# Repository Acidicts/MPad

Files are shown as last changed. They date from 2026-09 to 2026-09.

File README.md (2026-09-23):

# M-Pad
### Media-Pad (Media-Hackpad)

A Hackpad but this time made for media with 3 dedicated keys for Back, Play/Pause, and Skip along with volume controls via a rotary encoder.
Powered by kmk on circuitpython

<div>
    assembled model
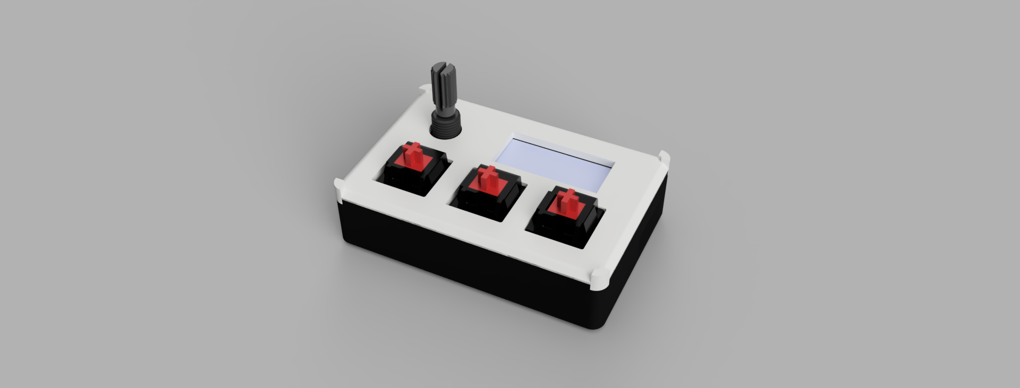
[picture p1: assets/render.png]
    
    <div style="display: inline-flex; justify-content: space-between; margin-top: 10px;">
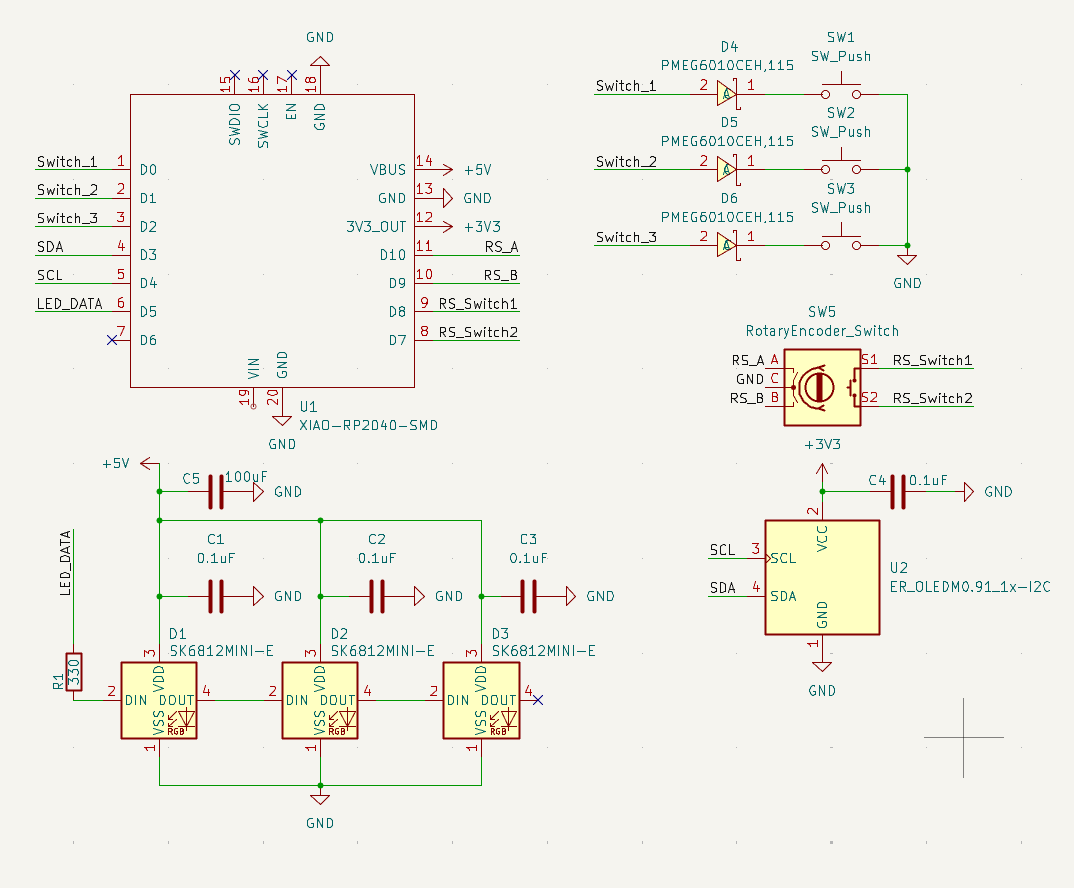
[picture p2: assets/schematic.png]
        
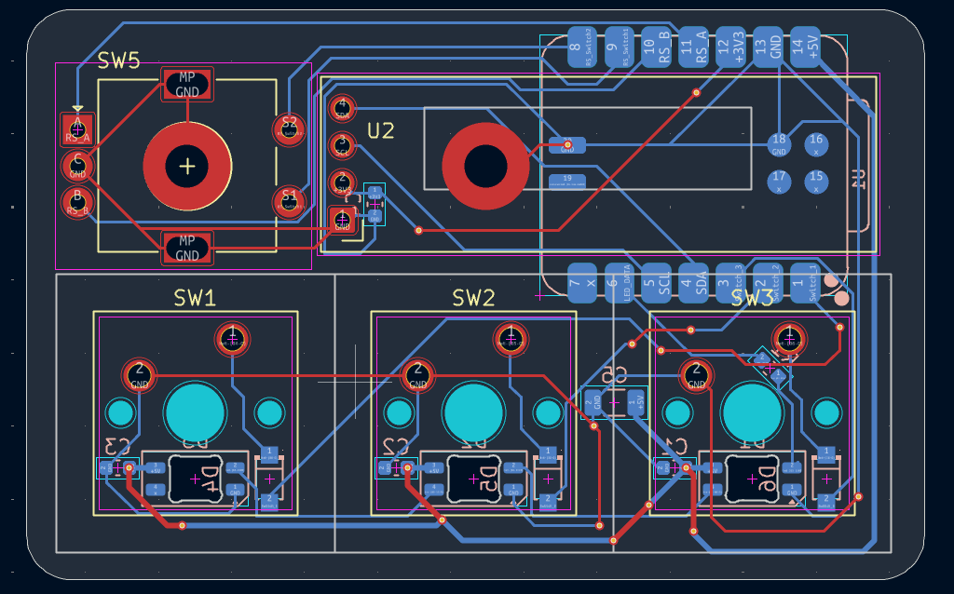
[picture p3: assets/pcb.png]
        
    </div>
</div>

### Case
- The lid is [here](./case/Lid.step)
- The case is [here](./case/Case.step)
- The Custom encoder knob is [here](./case/Encoder_Knob.step)
- The detachable stand that mounts in the two square holes in the back is [here](./case/Detachable_Stand.step)
- Fusion 360 file is [here](https://a360.co/4gD1b6e)

### Key Mappings
---
<div style="display: inline-flex; justify-content: space-between;">
    <div style="border-right: 1px solid #888; padding-right: 10px; margin-right: 10px;">
        <strong>Key Switches</strong>
        <table>
            <thead>
                <tr>
                    <th>Function</th>
                    <th>Key</th>
                </tr>
            </thead>
            <tbody>
                <tr><td>Back</td><td>KC.WBAK</td></tr>
                <tr><td>Play/Pause</td><td>KC.MPLY</td></tr>
                <tr><td>Skip</td><td>KC.WFWD</td></tr>
            </tbody>
        </table>
    </div>
    <div>
        <strong>Encoder Mapping</strong>
        <table>
            <thead>
                <tr>
                    <th>Function</th>
                    <th>Key</th>
                </tr>
            </thead>
            <tbody>
                <tr><td>Volume Down</td><td>KC.VOLD</td></tr>
                <tr><td>Volume Up</td><td>KC.VOLU</td></tr>
                <tr><td>Mute</td><td>KC.MUTE</td></tr>
            </tbody>
        </table>
    </div>
</div>

### BOM
---
- [BOM](./assets/BOM.csv)
- [LCSC Component BOM](./assets/LCSC_BOM.csv)

### Getting Started
1. Download the latest release of circuitpython from [here](https://downloads.circuitpython.org/bin/seeeduino_xiao_rp2040/en_GB/adafruit-circuitpython-seeeduino_xiao_rp2040-en_GB-10.3.0.uf2)
2. whilst powering the Seeed Studio XIAO RP2040, hold down the boot button and plug it into your computer. The board should show up as a USB drive called `RPI-RP2`.
3. Drag and drop the downloaded UF2 file onto the `RPI-RP2` drive. The board will reboot and show up as a USB drive called `CIRCUITPY`.
4. drag and drop the contents of the [`firmware`](./firmware) folder onto the `CIRCUITPY` drive.
5. Restart the board and it should now be ready to use.

~ Note It is configured for getting stock prices edit the firmware to do as you see fit
~ It uses [main.py](main.py) on the host to communicate over serial

### Soldering Guide
~ Note the capacitors and resistors on the pcb are optional, as they are for decoupling and filtering
1. Use flux on the surface of the pads
2. Place LEDS reverse mounted
3. Solder them
4. Position the diodes with the side with the line facing the same way as in the silk screen
5. Solder them on
6. Solder the ssd1306 oled display (128x32) so the long legs for it stick down
7. Place the m3 screw in the hole then put oled display over top and solder it on
8. Solder on the Xiao
9. solder on the keycaps
10. If you don't have the resistor, bridge the gap using solder
11. push in the EC11E rotary encoder and solder in
12. You're done!!!

### Want to edit the code
1. Hold the middle switch whilst plugging in the board to your computer. The board should show up as a USB drive called `CIRCUITPY`.
2. Edit it as if it is a normal drive. 

### Demo video

<video src="https://github.com/user-attachments/assets/15901fed-9ee6-4e93-8e1c-391db2670cf7" controls="controls" style="max-width: 100%;" title="Demo Video.mp4">
</video>

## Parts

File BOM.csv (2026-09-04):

What | Cost (total) | QTY | Source
PCB | $4.00 + $6.36 shipping | 5 | JLCPCB
Key Switches | $16.00 | 10 | Amazon
LCSC Components | $7.22 + $4.52 Shipping + $3.00 Handling | 1 | LCSC
Xiao Seeed Studio RP2040 | $3.90 + $3.80 shipping | 1 | Seeed Studio
0.91" Oled Display | $~2.50 + Free Shipping | 1 | AliExpress

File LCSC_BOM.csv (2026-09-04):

What | Cost (total of min amount) | QTY | Source
Rotary Encoder | $1.98 | 1 | LCSC
Diode | $1.61 | 3 (min 5 due to lcsc) | LCSC
Capacitor 100uF | $1.53 | 1 (min 10 due to lcsc) | LCSC
Capacitor 0.1uF | $1.08 | 4 (min 100 due to lcsc) | LCSC
Resistor 330 | $0.62 | 1 (min 100 due to lcsc) | LCSC
RGB LED | $0.40 | 3 (min 100 due to lcsc) | LCSC

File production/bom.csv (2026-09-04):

Designator | Footprint | Quantity | Value | LCSC Part #
C1, C2, C3, C4 | 0603 | 4 | 0.1uF | C1591
C5 | 1206 | 1 | 100uF | C15008
D1, D2, D3 | LED_SK6812MINI-E_3.2x2.8mm_P1.5mm_ReverseMount | 3 | SK6812MINI-E
D4, D5, D6 | SOD-123FL_L2.7-W1.8-LS3.8-RD | 3 | PMEG6010CEH,115 | C110797
R1 | 0603 | 1 | 330 | C105881
SW1, SW2, SW3 | SW_Cherry_MX_1.00u_PCB | 3 | SW_Push
SW5 | RotaryEncoder_Alps_EC11E-Switch_Vertical_H20mm | 1 | RotaryEncoder_Switch
U1 | XIAO-RP2040-SMD | 1 | XIAO-RP2040-SMD
U2 | ER_OLEDM0.91_1x-I2C | 1 | ER_OLEDM0.91_1x-I2C

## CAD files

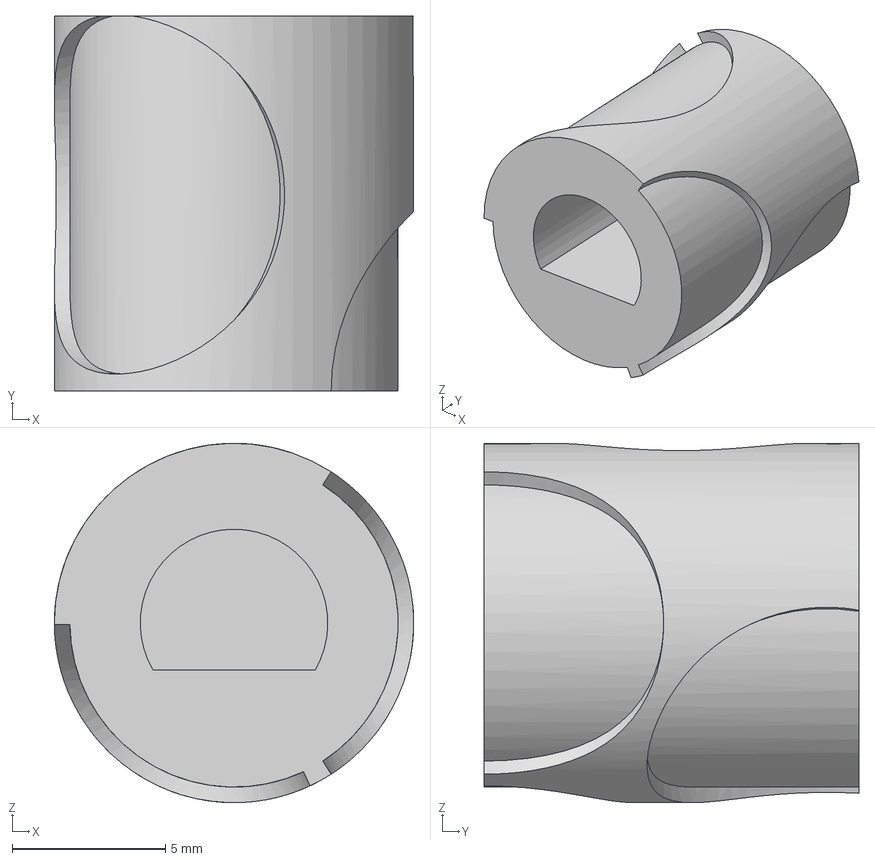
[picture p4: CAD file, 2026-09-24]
case/Encoder_Knob.step
11.7 x 12.2 x 11.7 mm

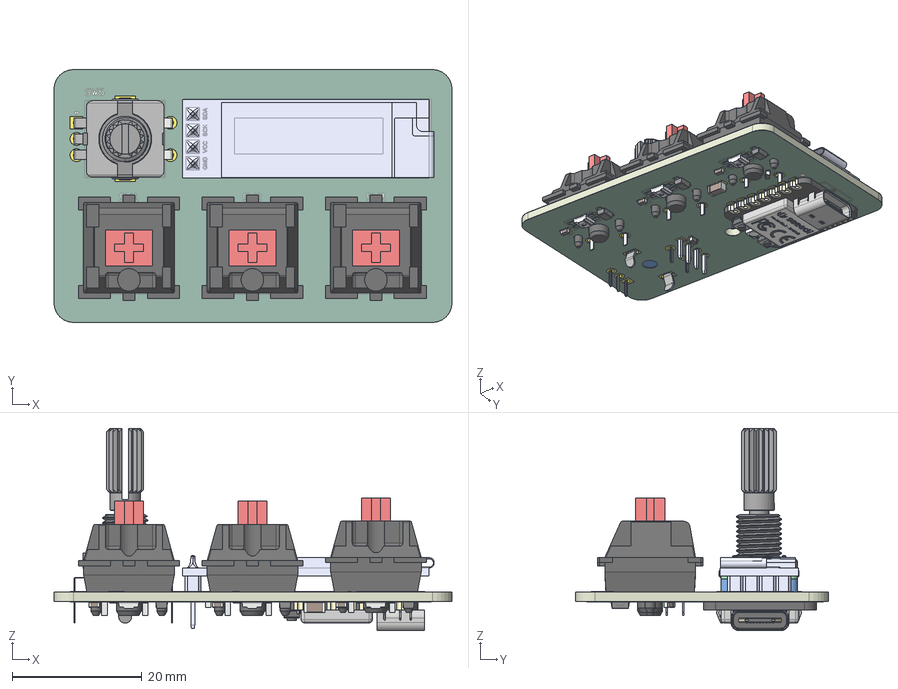
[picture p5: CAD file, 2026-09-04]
HackPad.step
61.4 x 39.0 x 31.2 mm
EC11_Rotary_Encoder_Switched
0.91in OLED
C_0603_1608Metric x 5
SOD-123_L2.8-W1.8-LS3.9-FD x 3
type-c v2
smd_button v3
DOUT
DIN
VSS
VDD
smd_button v3(Mirror)
Pin1 x 3
Pin2 x 3
Pin3 x 3
Pin4 x 3
C_1206_3216Metric
HackPad_copper
HackPad_silkscreen x 2
HackPad_soldermask x 2
HackPad_PCB

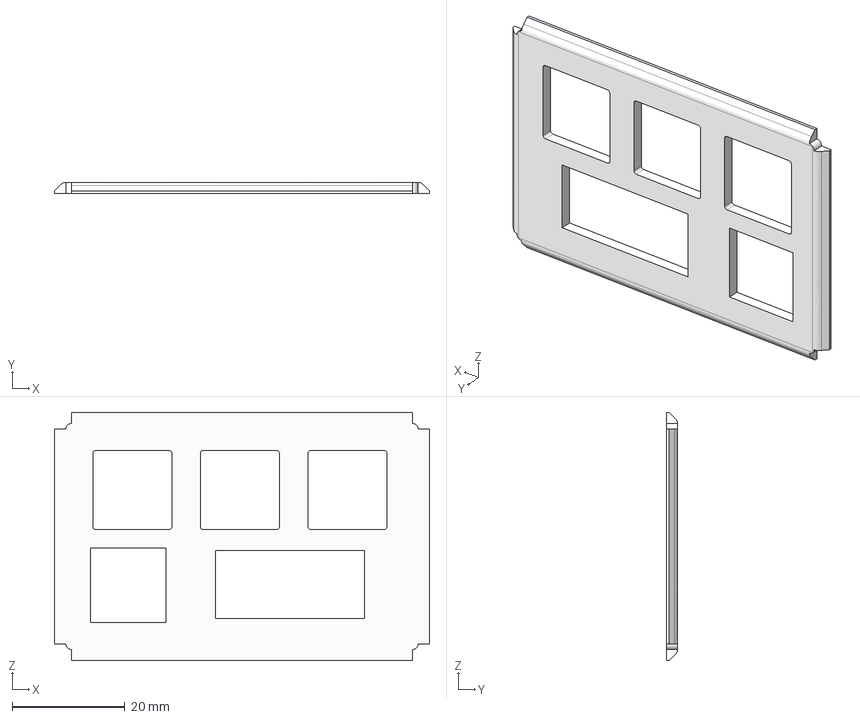
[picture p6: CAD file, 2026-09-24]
case/Lid.step
66.4 x 2.00 x 44.0 mm

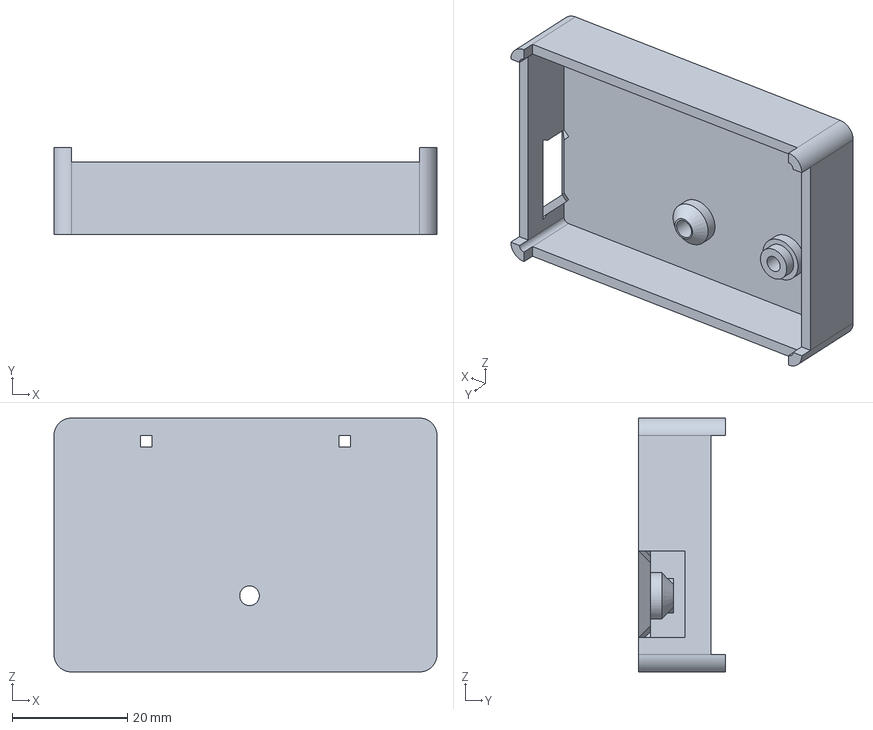
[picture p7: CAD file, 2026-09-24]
case/Case.step
66.4 x 15.0 x 44.0 mm

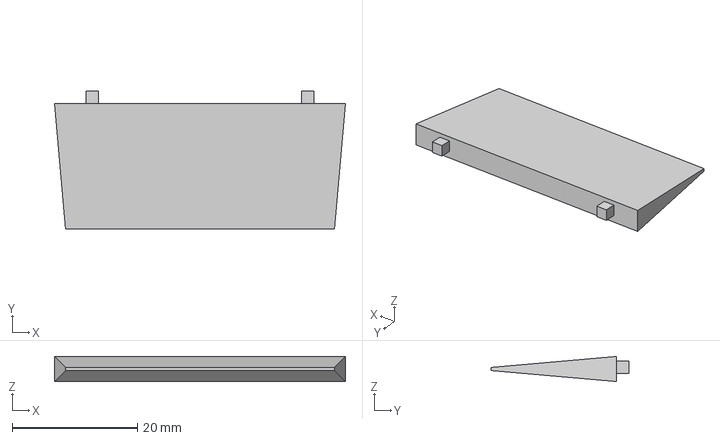
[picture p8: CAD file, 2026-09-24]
case/Detachable_Stand.step
46.4 x 22.0 x 4.00 mm

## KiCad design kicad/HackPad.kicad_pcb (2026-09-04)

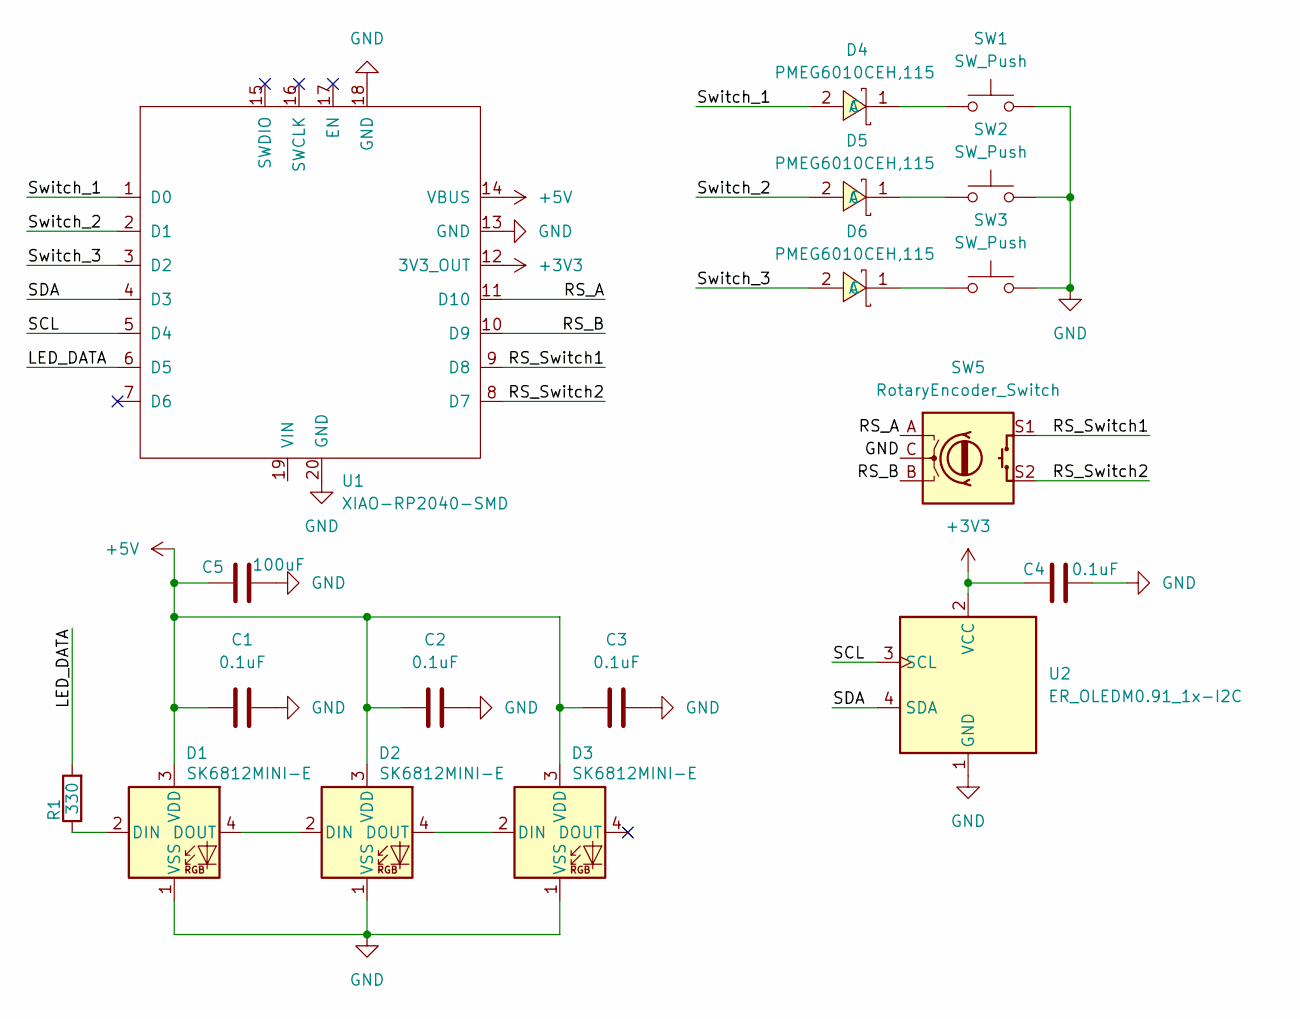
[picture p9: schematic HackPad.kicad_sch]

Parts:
C1, C2, C3, C4: 0.1uF; C_0603_1608Metric; LCSC C1591
C5: 100uF; C_1206_3216Metric; LCSC C15008
D1, D2, D3: SK6812MINI-E; LED_SK6812MINI-E_3.2x2.8mm_P1.5mm_ReverseMount
D4, D5, D6: PMEG6010CEH,115; SOD-123FL_L2.7-W1.8-LS3.8-RD; MPN PMEG6010CEH,115; LCSC Part C110797
R1: 330; C_0603_1608Metric; LCSC C105881
SW1, SW2, SW3: SW_Push; SW_Cherry_MX_1.00u_PCB
SW5: RotaryEncoder_Switch; RotaryEncoder_Alps_EC11E-Switch_Vertical_H20mm
U1: XIAO-RP2040-SMD
U2: ER_OLEDM0.91_1x-I2C

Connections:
+3V3: C4.1, U1.12 (3V3_OUT), U2.2 (VCC)
+5V: C1.1, C2.1, C3.1, C5.1, D1.3 (VDD), D2.3 (VDD), D3.3 (VDD), U1.14 (VBUS)
/LED_DATA: R1.2, U1.6 (D5)
/RS_A: SW5.A, U1.11 (D10)
/RS_B: SW5.B, U1.10 (D9)
/RS_Switch1: SW5.S1, U1.9 (D8)
/RS_Switch2: SW5.S2, U1.8 (D7)
/SCL: U1.5 (D4), U2.3 (SCL)
/SDA: U1.4 (D3), U2.4 (SDA)
/Switch_1: D4.2 (A), U1.1 (D0)
/Switch_2: D5.2 (A), U1.2 (D1)
/Switch_3: D6.2 (A), U1.3 (D2)
GND: C1.2, C2.2, C3.2, C4.2, C5.2, D1.1 (VSS), D2.1 (VSS), D3.1 (VSS), SW1.2, SW2.2, SW3.2, SW5.C, SW5.MP, U1.13 (GND), U1.18 (GND), U1.20 (GND), U2.1 (GND)
unnamed: D1.2 (DIN), R1.1
unnamed: D1.4 (DOUT), D2.2 (DIN)
unnamed: D2.4 (DOUT), D3.2 (DIN)
unnamed: D4.1 (C), SW1.1
unnamed: D5.1 (C), SW2.1
unnamed: D6.1 (C), SW3.1

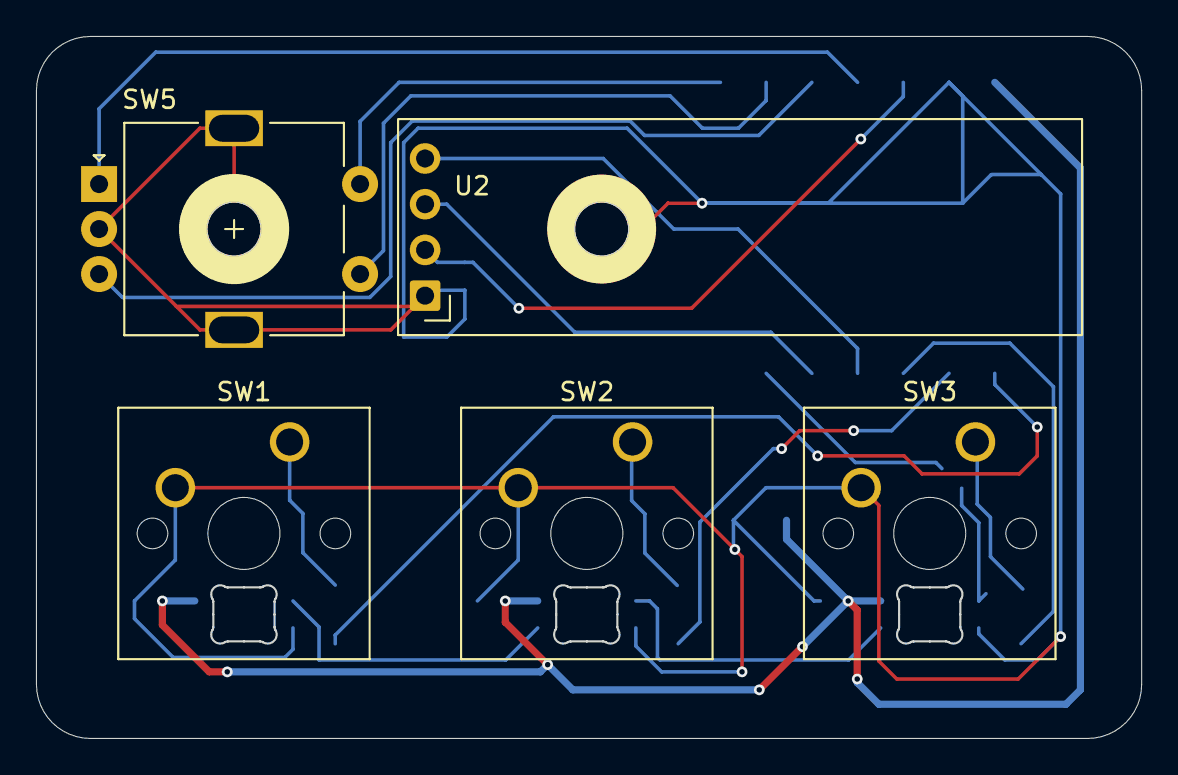
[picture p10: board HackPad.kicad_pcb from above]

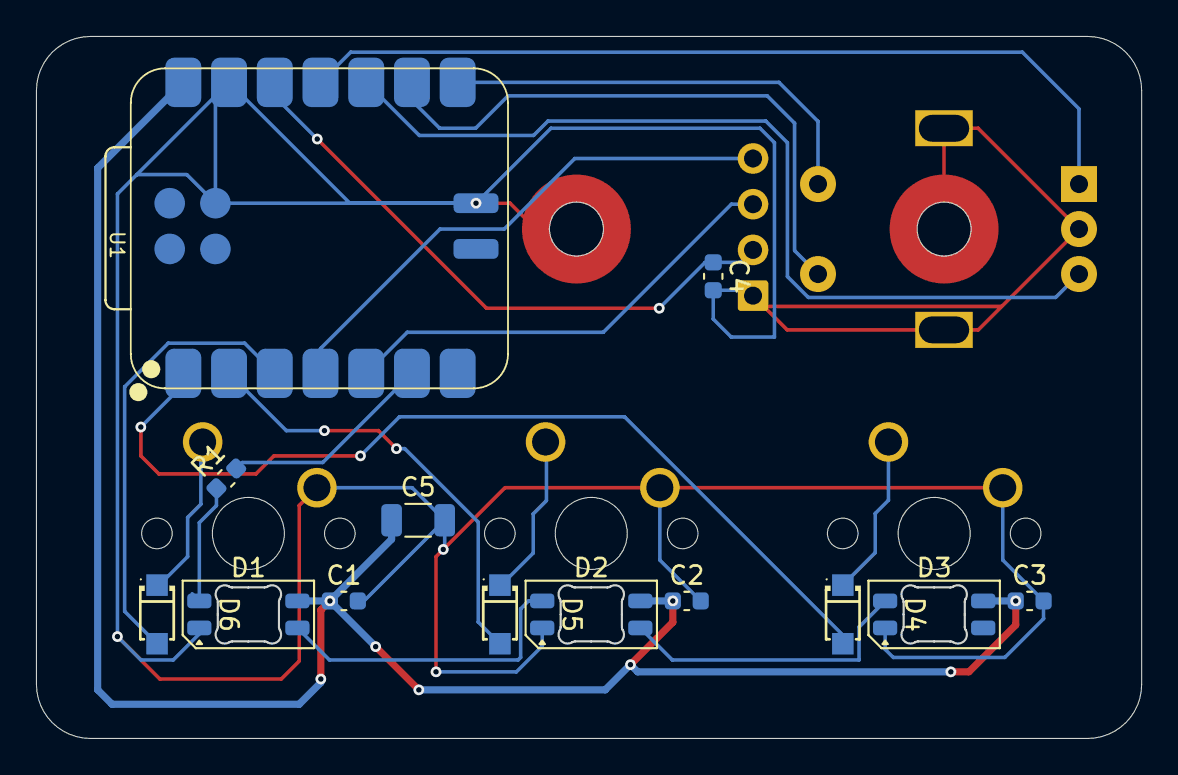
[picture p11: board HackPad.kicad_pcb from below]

Board: 2 copper layers, 61.4 x 39.0 mm, 18 parts (13 on the bottom side), 19 nets.

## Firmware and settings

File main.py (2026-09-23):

import time
import serial
import serial.tools.list_ports
import yfinance as yf

TICKER = "RR.L"          # Rolls-Royce Holdings (LSE, priced in pence)
INTERVAL = 30            # seconds between sends (pad goes STALE after 180)
VID, PID = 0x2886, 0x42  # Seeeduino XIAO RP2040 running CircuitPython
EXPECTED_PORTS = 2       # console + data


def find_pad_ports():
    return sorted(
        p.device
        for p in serial.tools.list_ports.comports()
        if p.vid == VID and p.pid == PID
    )


def open_ports(devices):
    opened = []
    for dev in devices:
        try:
            opened.append(serial.Serial(dev, 115200, timeout=1, write_timeout=2))
        except (serial.SerialException, OSError) as e:
            print(f"Could not open {dev}: {e}", flush=True)
    return opened


def close_all(ports):
    for p in ports:
        try:
            p.close()
        except Exception:
            pass


def get_quote(ticker):
    info = ticker.fast_info
    price = float(info["last_price"])
    prev = float(info["previous_close"])
    change = (price - prev) / prev * 100
    return price, change


def main():
    ticker = yf.Ticker(TICKER)
    ports = []
    last_quote = None      # (price, change), reused if Yahoo fails
    last_sent = 0
    last_fetch = 0

    while True:
        # If the pad's port set changed (unplug, re-enumeration), reconnect
        current = find_pad_ports()
        connected = sorted(p.port for p in ports)
        if ports and current != connected:
            print("Port set changed, reconnecting...", flush=True)
            close_all(ports)
            ports = []

        if not ports:
            if len(current) < EXPECTED_PORTS:
                print(f"Waiting for pad ({len(current)}/{EXPECTED_PORTS} ports)...", flush=True)
                time.sleep(3)
                continue
            ports = open_ports(current)
            if len(ports) < EXPECTED_PORTS:
                close_all(ports)
                ports = []
                time.sleep(3)
                continue
            print("Connected:", [p.port for p in ports], flush=True)
            last_sent = 0  # send immediately

        now = time.time()

        # Refresh the quote every 60s (don't hammer Yahoo)
        if now - last_fetch >= 60:
            try:
                last_quote = get_quote(ticker)
                last_fetch = now
            except Exception as e:
                print("Fetch failed:", e, flush=True)
                last_fetch = now - 50  # retry in ~10s

        # Send the latest known quote every INTERVAL seconds
        if last_quote and now - last_sent >= INTERVAL:
            price, change = last_quote
            msg = f"{TICKER},{price:.2f},{change:+.2f}\n".encode()
            try:
                for p in ports:
                    p.write(msg)
                    p.flush()
                print(f"Sent: {price:.2f}p ({change:+.2f}%)", flush=True)
                last_sent = now
            except (serial.SerialException, OSError):
                print("Write failed, reconnecting...", flush=True)
                close_all(ports)
                ports = []
                continue

        time.sleep(1)


if __name__ == "__main__":
    main()

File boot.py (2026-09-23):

# boot.py
import usb_cdc
import storage
import board
import digitalio

# --- Enable the second USB serial port for the PC stock script ---
usb_cdc.enable(console=True, data=True)

# --- Optional: hide the CIRCUITPY drive during normal use ---
# Hold the first key (D0) while plugging in to keep the drive visible for editing.
# Without this held, the drive is hidden and the pad behaves like a plain keyboard.
button = digitalio.DigitalInOut(board.D0)
button.direction = digitalio.Direction.INPUT
button.pull = digitalio.Pull.UP

if button.value:  # not held (pull-up: True means not pressed)
    storage.disable_usb_drive()
    # storage.remount("/", readonly=False)  # uncomment if main.py needs to write files

button.deinit()
